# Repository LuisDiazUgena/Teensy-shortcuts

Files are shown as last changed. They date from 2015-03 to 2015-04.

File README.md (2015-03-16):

# Teensy-shortcuts

This programm is a shortcut manager for applications on your computer.
Up to 4 profiles (easy to implement more).
Up to 6 buttons with display info of each one. It's really simple to add more, but without showing info in the LCD Screen.

## Hardware

Use a Teensy 3.1 board, pushbuttons and a LCD to display the current Profile.

## Usage

The program is bassed on pushbuttons that send keyboard strokes on their rising edge.
Just click the button and let the magic happend!
## Software supported

1. Arduino IDE:
  1.  Verify
  2.  Upload
  3.  Monitor
  4.  Auto Format
2. Sublime Text 3 with Stino plugin :
  1.  Verify
  2.  Upload
  3.  Monitor
  4.  Auto Format

##How to: Add pushbuttons

1. Connect the pushbutton to a digital pin. Use a pulldown resistror to pushbuttons.
2. Create a Bounce objet to debounce the pushbutton:
<pre lang="arduino"><code>
  Bounce *name_of_your_button* = Bounce(*pin_of_your_button*,10);
</code></pre>
3. Use:
<pre lang="arduino"><code>
  pinMode(*pinNumer or variable*,INPUT);
</code></pre>
4. At <pre lang="Arduino">profileActions</pre> update the button, then watch for the risindEdge of that button and send keystrokes. ie:

<pre lang="arduino"><code>

  btn1.update();
   
  if (btn1.risingEdge()){
    Serial.println("risingEdge btn1");
    Keyboard.set_modifier(MODIFIERKEY_CTRL);
    Keyboard.set_key1(KEY_R);
    Keyboard.send_now();

  }
</code></pre>

##How to: Add program profile

Create a profile struct:
<pre lang="arduino"><code>    
  struct Profile profile1;
</code></pre>

Add profile name and shortcuts names:

<pre lang="arduino"><code>    
  strcpy (profile1.name,"Arduino IDE");
  strcpy (profile1.shortcut1,"Verify");
  strcpy (profile1.shortcut2,"Upload");
  strcpy (profile1.shortcut3,"Monitor");
  strcpy (profile1.shortcut4,"AutoFormat");
</code></pre>

Add shortcuts inside of <pre lang="arduino"><code>profileActions</code></pre> function

##How to: Add shortcuts

Check out your favorite program shortcuts and know which key combination activate them, then go to [teensy keys](https://www.pjrc.com/teensy/td_keyboard.html) and look for your keys combination.

Place them inside of:
<pre lang="arduino"><code>    
    if (name_of_your_button.risingEdge()){
      //Send keystrokes
    }
</code></pre>

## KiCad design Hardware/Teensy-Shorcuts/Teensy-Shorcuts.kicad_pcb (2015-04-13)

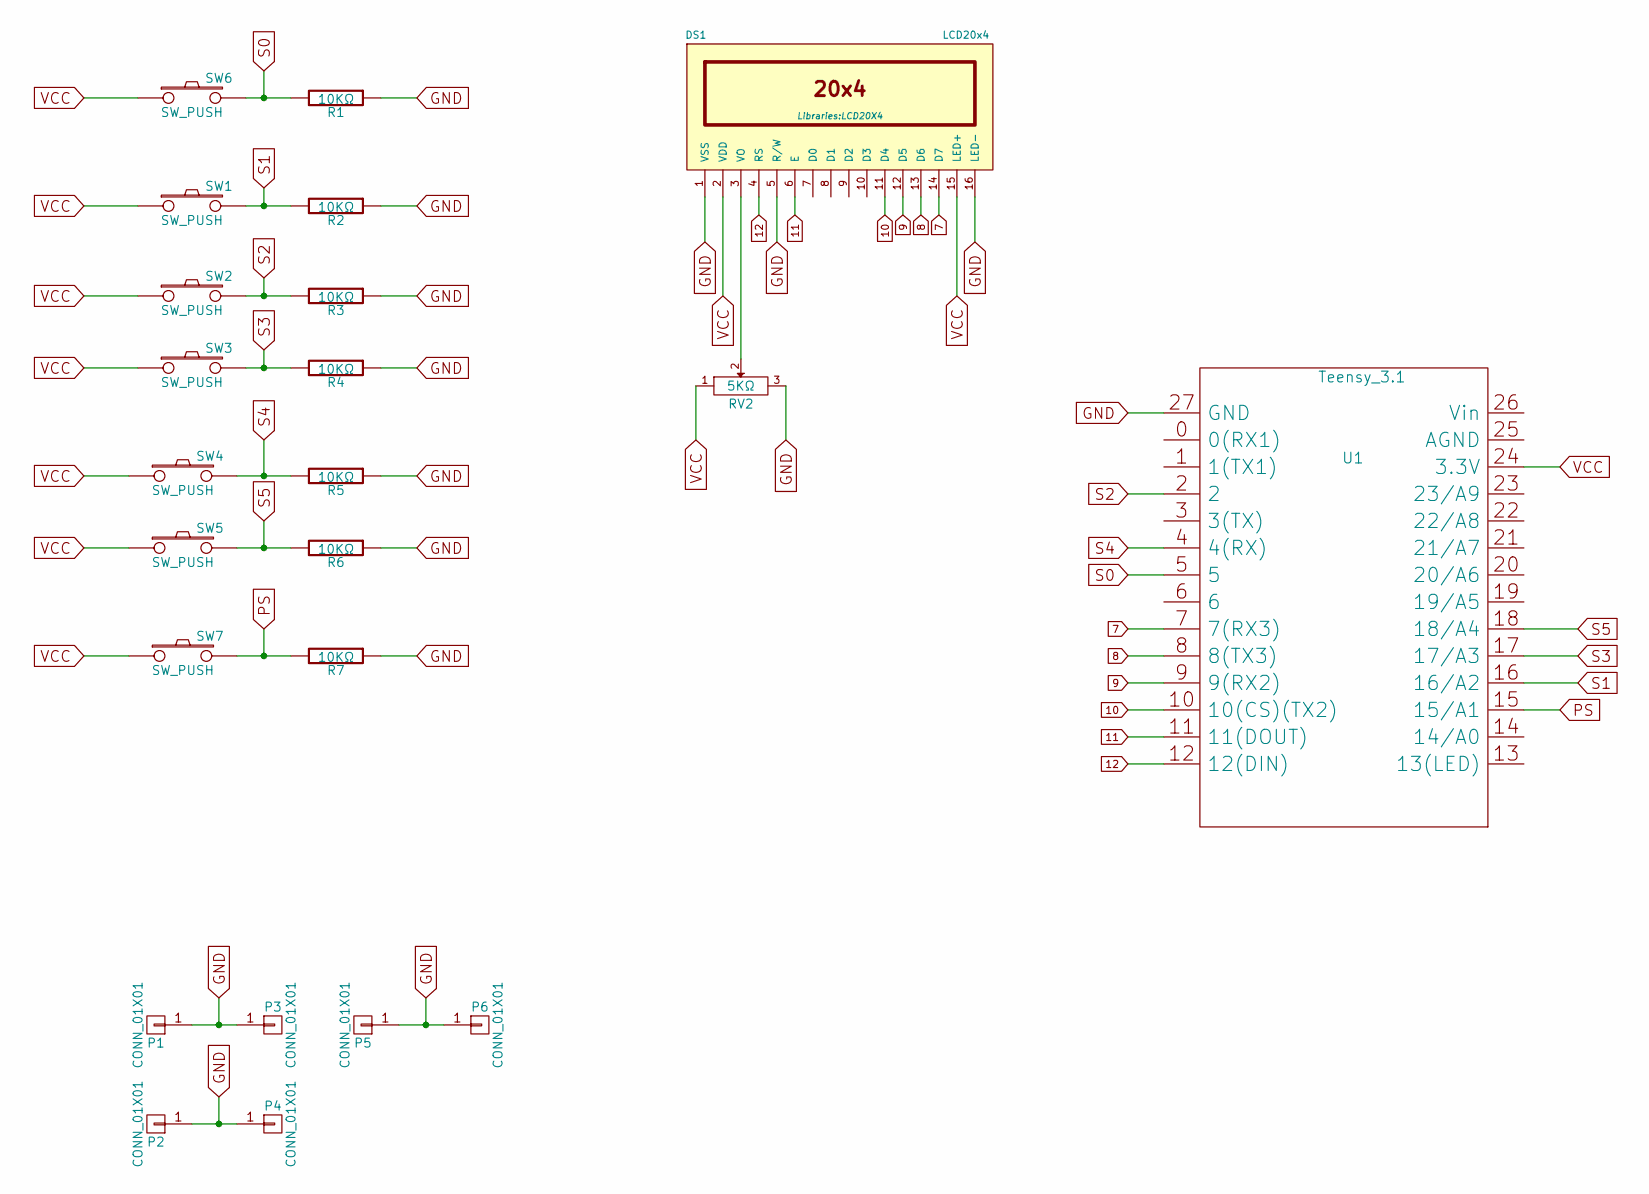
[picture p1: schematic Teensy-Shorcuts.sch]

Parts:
DS1: LCD20x4; LCD20X4
P1, P2, P3, P4, P5, P6: CONN_01X01; Jumper1x01
R1, R2, R3, R4, R5, R6, R7: 10KΩ; Res
RV2: 5KΩ; trimmer
SW1, SW2, SW3, SW4, SW5, SW6, SW7: SW_PUSH; Switch
U1: Teensy_3.1; Teensy-3.1

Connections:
7: DS1.14 (D7), U1.7 (7(RX3))
8: DS1.13 (D6), U1.8 (8(TX3))
9: DS1.12 (D5), U1.9 (9(RX2))
10: DS1.11 (D4), U1.10 (10(CS)(TX2))
11: DS1.6 (E), U1.11 (11(DOUT))
12: DS1.4 (RS), U1.12 (12(DIN))
GND: DS1.1 (VSS), DS1.5 (R/W), DS1.16 (LED-), P1.1, P2.1, P3.1, P4.1, P5.1, P6.1, R1.1, R2.1, R3.1, R4.1, R5.1, R6.1, R7.1, RV2.3, U1.27 (GND)
unnamed: DS1.3 (VO), RV2.2
PS: R7.2, SW7.2, U1.15 (15/A1)
S0: R1.2, SW6.2, U1.5
S1: R2.2, SW1.2, U1.16 (16/A2)
S2: R3.2, SW2.2, U1.2
S3: R4.2, SW3.2, U1.17 (17/A3)
S4: R5.2, SW4.2, U1.4 (4(RX))
S5: R6.2, SW5.2, U1.18 (18/A4)
VCC: DS1.2 (VDD), DS1.15 (LED+), RV2.1, SW1.1, SW2.1, SW3.1, SW4.1, SW5.1, SW6.1, SW7.1, U1.24 (3.3V)

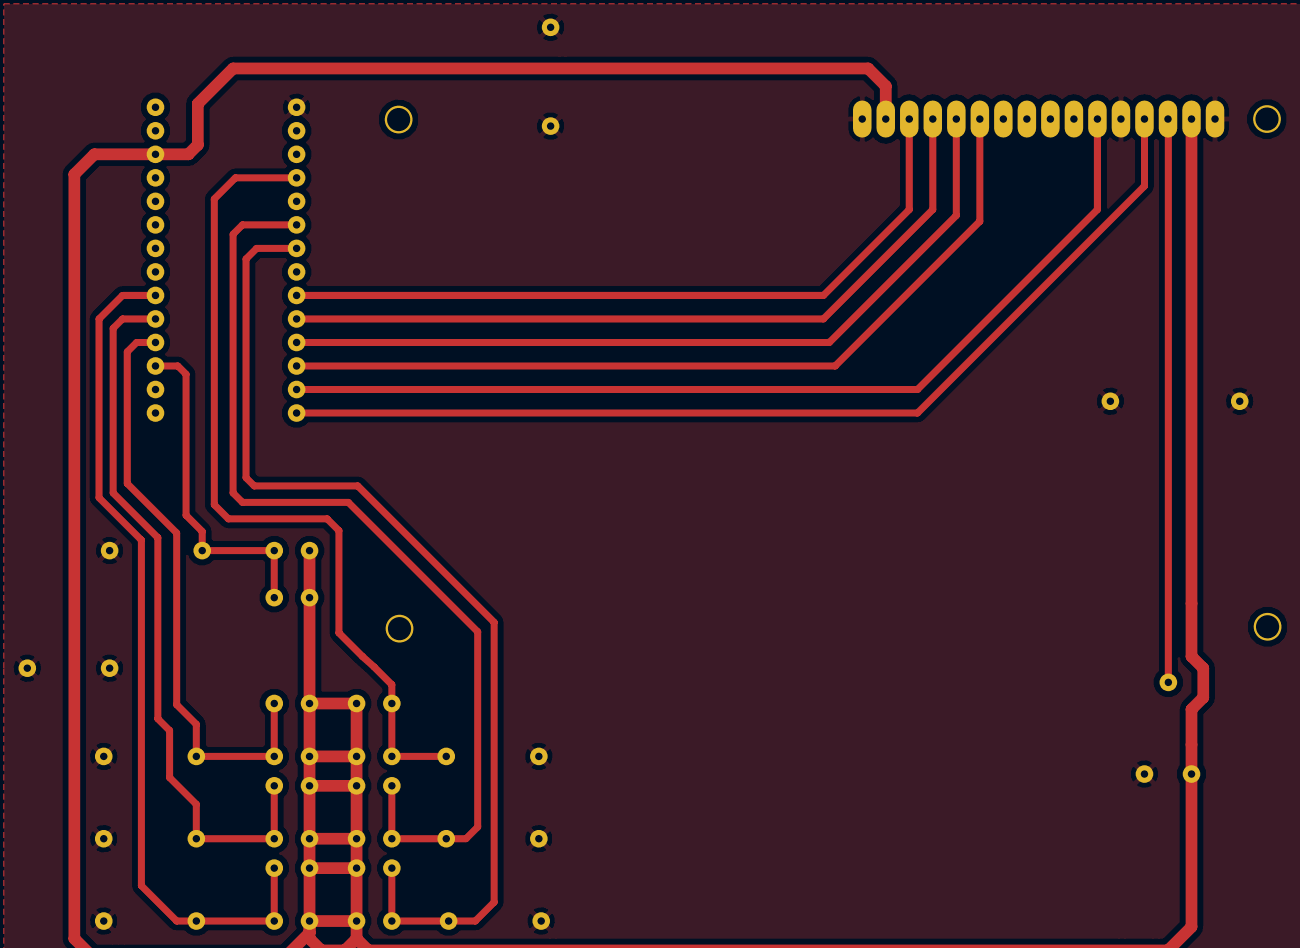
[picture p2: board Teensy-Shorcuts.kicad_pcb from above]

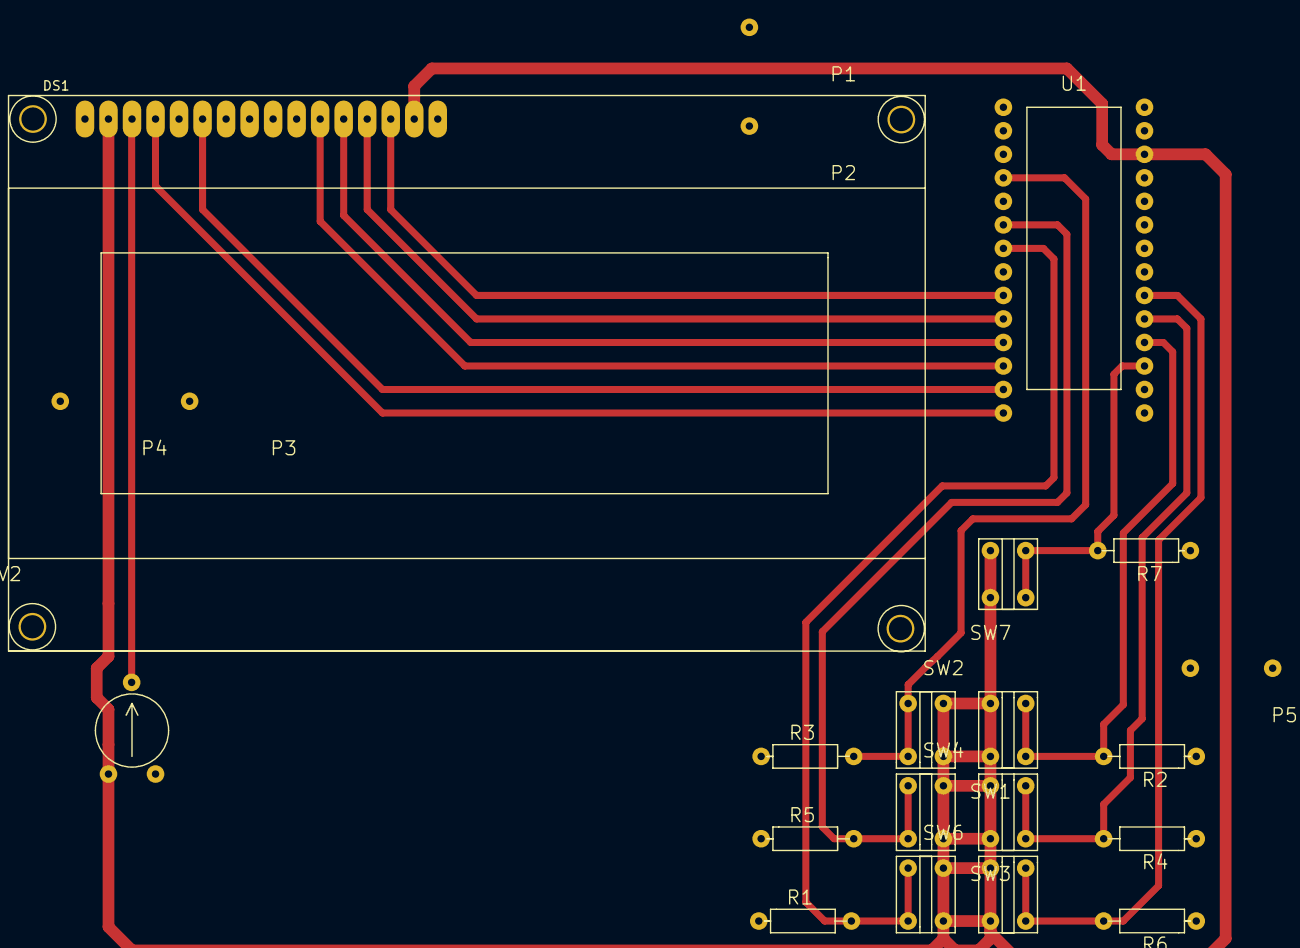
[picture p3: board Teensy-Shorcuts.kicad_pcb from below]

Board: 2 copper layers, 23 parts (23 on the bottom side), 16 nets.

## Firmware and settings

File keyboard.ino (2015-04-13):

/*

USB keyboard shortcut manager
Teensy 3.1 working as usb keyboard
Luis Diazains...


*/
struct Profile {

  char name[20];
  char shortcut1[10];
  char shortcut2[10];
  char shortcut3[10];
  char shortcut4[10];
  char shortcut5[10];
  char shortcut6[10];

};

//Libraries
#include <LiquidCrystal.h>
#include <Bounce.h>
#include <usb_keyboard.h>
#include <string.h>

int pinBtn1 = 0, pinBtn2 = 1, pinBtn3 = 2, pinBtn4 = 3, pinBtn5 = 4, pinBtn6 = 5;
int pinPS = 15;

// initialize the library with the numbers of the interface pins
LiquidCrystal lcd(12, 11, 10, 9, 8, 7);

//Create buttons with software debounce
Bounce btn1 = Bounce(pinBtn1, 10);
Bounce btn2 = Bounce(pinBtn2, 10);
Bounce btn3 = Bounce(pinBtn3, 10);
Bounce btn4 = Bounce(pinBtn4, 10);
Bounce btn5 = Bounce(pinBtn5, 10);
Bounce btn6 = Bounce(pinBtn6, 10);
Bounce btnPS = Bounce(pinPS, 10);

//Profile Selector
int aktProfile = 2, lastProfile = 0;
int profile_number = 3;

//Profiles

struct Profile profile1;
struct Profile profile2;
struct Profile profile3;
struct Profile profile4;

void setup() {

  pinMode(pinBtn1, INPUT_PULLUP);
  pinMode(pinBtn2, INPUT_PULLUP);
  pinMode(pinBtn3, INPUT_PULLUP);
  pinMode(pinBtn4, INPUT_PULLUP);
  pinMode(pinBtn5, INPUT_PULLUP);
  pinMode(pinBtn6, INPUT_PULLUP);
  pinMode(pinPS, INPUT_PULLUP);

  //pinMode(pinProfileSelector, INPUT);

  // set up the LCD's number of columns and rows:
  lcd.begin(20, 4);

  // Print a message to the LCD.
  lcd.print("Teensy shortcuts!");
  lcd.setCursor(0, 3);
  lcd.print("Luis Diaz");
  delay(1000);
  lcd.clear();

//Add values to the struct

//Initialize profiles

//Profile1
  strcpy (profile1.name, "Arduino IDE");
  strcpy (profile1.shortcut1, "Verify");
  strcpy (profile1.shortcut2, "Upload");
  strcpy (profile1.shortcut3, "Monitor");
  strcpy (profile1.shortcut4, "AutoFormat");

//profile2
  strcpy (profile2.name, "Sublime 3");
  strcpy (profile2.shortcut1, "Fold All");
  strcpy (profile2.shortcut2, "Upload");
  strcpy (profile2.shortcut3, "Monitor");
  strcpy (profile2.shortcut4, "AutoFormat");


  //profile3
  strcpy (profile3.name, "Html Editor");
  strcpy (profile3.shortcut1, "h2");
  strcpy (profile3.shortcut2, "em");
  strcpy (profile3.shortcut3, "strong");
  strcpy (profile3.shortcut4, "pre Arduin");

}

void loop() {


  btnPS.update();

  if (btnPS.risingEdge()) {
    Serial.println("NextProfile");
    aktProfile++;
    if (aktProfile > profile_number) {
      aktProfile = 1;
    }
  }

  printProfile(aktProfile);
  profileActions(aktProfile);

}
//

void profileActions(int aktProfile) {

  btn1.update();
  btn2.update();
  btn3.update();
  btn4.update();
  btn5.update();
  btn6.update();


  switch (aktProfile) {
  // Profile 1
  case 1:

    if (btn1.risingEdge()) {
      Keyboard.set_modifier(MODIFIERKEY_CTRL);
      Keyboard.set_key1(KEY_R);
      Keyboard.send_now();
    }
    if (btn2.risingEdge()) {
      Keyboard.set_modifier(MODIFIERKEY_CTRL);
      Keyboard.set_key1(KEY_U);
      Keyboard.send_now();
    }
    if (btn3.risingEdge()) {
      Keyboard.set_modifier(MODIFIERKEY_CTRL);
      Keyboard.send_now();
      Keyboard.set_modifier(MODIFIERKEY_CTRL | MODIFIERKEY_SHIFT );
      Keyboard.set_key1(KEY_M);
      Keyboard.send_now();
    }
    if (btn4.risingEdge()) {
      Keyboard.set_modifier(MODIFIERKEY_CTRL);
      Keyboard.set_key1(KEY_T);
      Keyboard.send_now();
    }
    break;
  // Profile 2
  case 2:
    if (btn1.risingEdge()) {
      Keyboard.set_modifier(MODIFIERKEY_CTRL);
      Keyboard.send_now();
      Keyboard.set_modifier(MODIFIERKEY_CTRL | MODIFIERKEY_SHIFT );
      Keyboard.set_key1(KEY_D);
      Keyboard.send_now();
    }
    if (btn2.risingEdge()) {
      Keyboard.set_modifier(MODIFIERKEY_CTRL);
      Keyboard.send_now();
      Keyboard.set_modifier(MODIFIERKEY_CTRL | MODIFIERKEY_ALT );
      Keyboard.set_key1(KEY_U);
      Keyboard.send_now();
    }
    if (btn3.risingEdge()) {
      Keyboard.set_modifier(MODIFIERKEY_CTRL);
      Keyboard.send_now();
      Keyboard.set_modifier(MODIFIERKEY_CTRL | MODIFIERKEY_ALT );
      Keyboard.set_key1(KEY_M);
      Keyboard.send_now();
    }
    if (btn4.risingEdge()) {
      // Autoformat working with Sublime Text 2 & 3 AStyle Formatter Plugin by timonwong
      // https://github.com/timonwong/SublimeAStyleFormatter
      Keyboard.set_modifier(MODIFIERKEY_CTRL);
      Keyboard.send_now();
      Keyboard.set_modifier(MODIFIERKEY_CTRL | MODIFIERKEY_ALT );
      Keyboard.set_key1(KEY_F);
      Keyboard.send_now();
    }
    break;
  // Profile 3
  case 3:

    // Strings profile3
    String header = "<h2></h2>", italic = "<em></em>", preArduino = "<pre lang=\"arduino\"></pre>", strong = "<strong></strong>";

    if (btn1.risingEdge()) {
      Keyboard.print(header);
      goingBack(5);
    }

    if (btn2.risingEdge()) {
      Keyboard.print(italic);
      goingBack(5);
    }
    
    if (btn3.risingEdge()) {
      Keyboard.print(strong);
      goingBack(9);
    }
    if (btn4.risingEdge()) {
      Keyboard.print(preArduino);
      goingBack(6);
    }

  }

  Keyboard.set_modifier(0);
  Keyboard.set_key1(0);
  Keyboard.send_now();

}

void goingBack(int pos) {

  int aktPos;
  
  for (aktPos = 0; aktPos < pos ; aktPos++) {
    Keyboard.set_key1(KEY_LEFT);
    Keyboard.send_now();
    Keyboard.set_modifier(0);
    Keyboard.set_key1(0);
    Keyboard.send_now();
  }

}

void printProfile(int aktProfile) {

  // set the cursor to column 0, line 1
  // (note: line 1 is the second row, since counting begins with 0):
  lcd.setCursor(0, 0);
  // print the number of seconds since reset:
  lcd.print("Profile: ");
  lcd.setCursor(9, 0);

  if (lastProfile != aktProfile ) {
    lcd.clear();
  }

  lastProfile = aktProfile;

  switch (aktProfile) {
  case 1:
    lcd.print(profile1.name);
    lcd.setCursor(0, 1);
    lcd.print(profile1.shortcut1);
    lcd.setCursor(10, 1);
    lcd.print(profile1.shortcut2);
    lcd.setCursor(0, 2);
    lcd.print(profile1.shortcut3);
    lcd.setCursor(10, 2);
    lcd.print(profile1.shortcut4);
    lcd.setCursor(0, 3);
    lcd.print(profile1.shortcut5);
    lcd.setCursor(10, 3);
    lcd.print(profile1.shortcut6);
    break;
  case 2:
    lcd.print(profile2.name);
    lcd.setCursor(0, 1);
    lcd.print(profile2.shortcut1);
    lcd.setCursor(10, 1);
    lcd.print(profile2.shortcut2);
    lcd.setCursor(0, 2);
    lcd.print(profile2.shortcut3);
    lcd.setCursor(10, 2);
    lcd.print(profile2.shortcut4);
    lcd.setCursor(0, 3);
    lcd.print(profile2.shortcut5);
    lcd.setCursor(10, 3);
    lcd.print(profile2.shortcut6);

    break;
  case 3:
    lcd.print(profile3.name);
    lcd.setCursor(0, 1);
    lcd.print(profile3.shortcut1);
    lcd.setCursor(10, 1);
    lcd.print(profile3.shortcut2);
    lcd.setCursor(0, 2);
    lcd.print(profile3.shortcut3);
    lcd.setCursor(10, 2);
    lcd.print(profile3.shortcut4);
    lcd.setCursor(0, 3);
    lcd.print(profile3.shortcut5);
    lcd.setCursor(10, 3);
    lcd.print(profile3.shortcut6);
    break;
  case 4:
    lcd.print(profile4.name);
    lcd.setCursor(0, 1);
    lcd.print(profile4.shortcut1);
    lcd.setCursor(10, 1);
    lcd.print(profile4.shortcut2);
    lcd.setCursor(0, 2);
    lcd.print(profile4.shortcut3);
    lcd.setCursor(10, 2);
    lcd.print(profile4.shortcut4);
    lcd.setCursor(0, 3);
    lcd.print(profile4.shortcut5);
    lcd.setCursor(10, 3);
    lcd.print(profile4.shortcut6);

    break;
  }
}

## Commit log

2015-03-12 initial commit. Added suport for arduino ide
2015-03-12 Added functions: selectProfile, printProfile, profileActions
2015-03-14 Started to work on Hardware
    [Teensy-Shorcuts.kicad_pcb, Teensy-Shorcuts.sch]
2015-03-15 Added pushbuttons and lcd schematics
2015-03-15 added profile selector trimmer
    [Teensy-Shorcuts.sch]
2015-03-16 added teensy 3.1/teensy 3.1 library created
    [Teensy-Shorcuts.sch]
2015-03-16 modified Teensy library
2015-03-16 added Teensy3.1 pinout
2015-03-16 Created Schematichs and PCB board layaot
    [$Teensy-Shorcuts.sch, Teensy-Shorcuts.sch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]
2015-03-16 Deleted gerber test
    [Teensy-Shorcuts-F_Cu.gbr]
2015-03-17 modified Pcb layout
    [Teensy-Shorcuts.kicad_pcb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]
2015-03-17 Modified pcb traces to delete 90º angles
    [Teensy-Shorcuts.sch]
2015-03-18 Modified pushbuttons to fit real pushbuttons
    [$Teensy-Shorcuts.sch, Teensy-Shorcuts.kicad_pcb]
2015-04-13 Adjust switch module to fit better real part
2015-04-13 moved html editor shortcuts text to string variables
    [keyboard.ino]
2015-04-13 Improved footprints to adjust better to real part
    [Teensy-Shorcuts.kicad_pcb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]
